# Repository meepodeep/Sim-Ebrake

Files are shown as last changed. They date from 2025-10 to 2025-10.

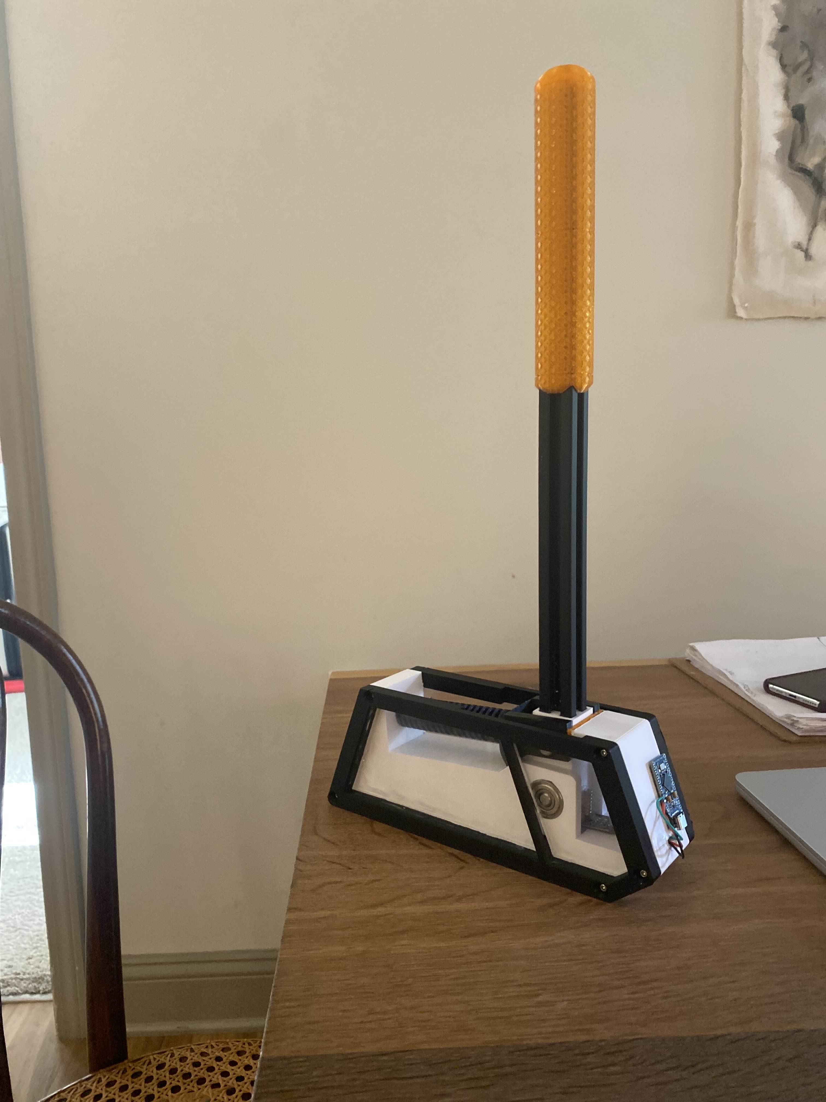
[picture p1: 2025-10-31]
ebrake.jpg

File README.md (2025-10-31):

# 2020 Brake
Racing sim Ebrake that has the same bolt pattern as the Moza!
ebrake

## Why does this exist?
  I wanted an ebrake but all of the existing solutions either looked kind of boring or were extremely expensive (moza handbrake). 
# Build
## Assembly
  1. Press the handle and bottom piece onto the V slot aluminum
  
  
  2. Mark and drill an 8mm hole through the bottom of the aluminum where the top hole in the plastic is
  3. Wire the hall sensor and pro micro like this
     
  
  
  5. Put the pro micro on the front after feeding the wires through the hole and secure it with tape or hot glue
  
  7. Double sided tape the hall sensor here
     
 

  9. Hot glue the magnets here
      
 

  11. Press fit bearings in each side of the base
      
  
  
  13. Put a rod through the bearings and shaft
  14. Attach the spring pivot like this
      
  
  
  16. Insert the spring here
      
  
  
  18. Attach the side panels (optionally add the acrylic inserts)
      
  

## Software
  ### https://github.com/ranenbg/Arduino-FFB-wheel
  1. Download the Xloader folder
  2. Run the .exe
  3. Click upload once you have selected the correct port and the correct hex file as according to the guide on ranebgs github

## BOM
|Item |Quantity |Total price+Shipping|Use In project |Item Source |
|---|---|---|---|---|
|Bearings 8x22x7mm |10pcs min purchase 2 used |$6.36 |Rotates the main pivot |https://www.aliexpress.us/item/3256807915662185.html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 |
|Magnets 5x2mm |10pcs min purchase 1 used |$1.80 |Magnets |https://www.aliexpress.us/item/3256809772407336.html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 |
|KY-035 Hall Sensor |2pcs for 20 cents more these are not very reliable 1 used|$2.85 |Senses the halls (Magnet)|https://www.aliexpress.us/item/3256806209950505.html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 |
|Pro Micro usbc |1x |$7.05 |Controls everything |https://www.aliexpress.us/item/3256806468327207.html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 |
|Spring Blue/whatever color 20x10x80mm|1x |$4.80 |Spring tension |https://www.aliexpress.us/item/3256806244146198.html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 |
|Pins 8x40mm |10pcs min purchase 2 used |$6.78 |pivot points |https://www.aliexpress.us/item/3256806373526334.html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 |
|2020 V slot 350mm |1x |$12.84 |shaft |https://www.aliexpress.us/item/3256803241979487.html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|
|Optional(Laser cut acrylic) |1x |$8 |COOOOL lookin sides |My uni makerspace |
|Tax |Its tax |$2.98 |Taxes | |
|TOTAL | |$53.46 | | |

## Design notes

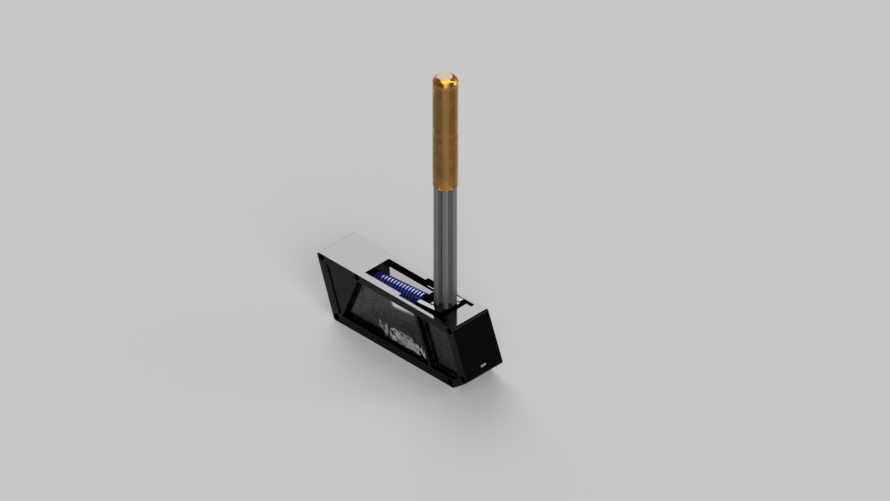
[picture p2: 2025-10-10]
ebrake render.png

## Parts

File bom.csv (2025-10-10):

Item | Quantity | Total price+Shipping | Use In project | Item Source
Bearings 8x22x7mm | 10pcs min purchase 2 used | $6.36 | Rotates the main pivot | https://www.aliexpress.us/item/3256807915662185.html?mp=1
Magnets 5x2mm | 10pcs min purchase 1 used | $1.80 | Magnets | https://www.aliexpress.us/item/3256809772407336.html?mp=1
KY-035 Hall Sensor | 2pcs for 20 cents more these are not very reliable 1 used | $2.85 | Senses the halls (Magnet) | https://www.aliexpress.us/item/3256806209950505.html?mp=1
Pro Micro usbc | 1x | $7.05 | Controls everything | https://www.aliexpress.us/item/3256806468327207.html?mp=1
Spring Blue/whatever color 20x10x80mm | 1x | $4.80 | Spring tension | https://www.aliexpress.us/item/3256806244146198.html?mp=1
Pins 8x40mm | 10pcs min purchase 2 used | $6.78 | pivot points | https://www.aliexpress.us/item/3256806373526334.html?mp=1
2020 V slot 350mm | 1x | $12.84 | shaft | https://www.aliexpress.us/item/3256803241979487.html?mp=1
Optional(Laser cut acrylic) | 1x | $8 | COOOOL lookin sides | My uni makerspace
Tax | Its tax | $2.98 | Taxes
TOTAL |  | $53.46

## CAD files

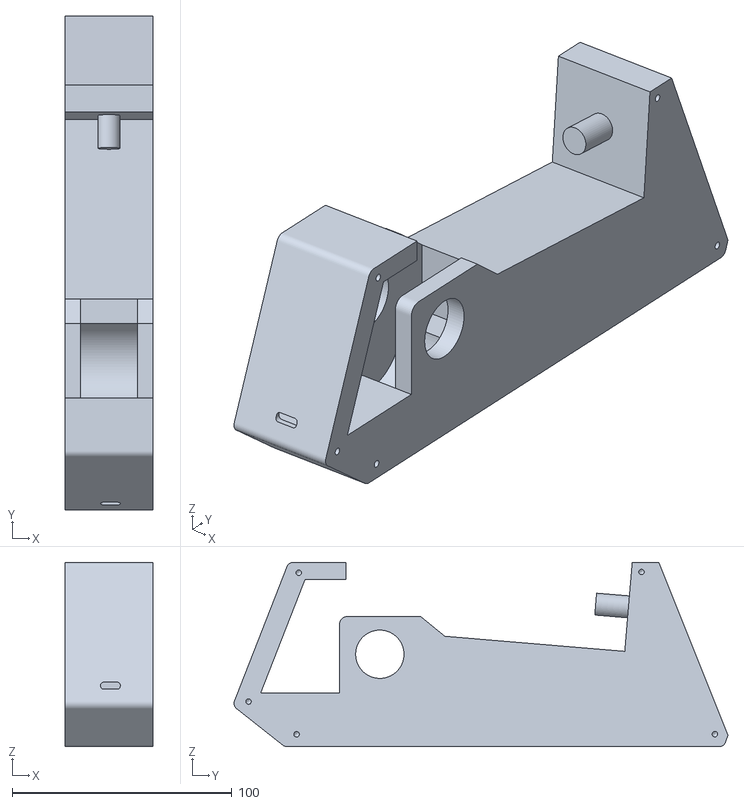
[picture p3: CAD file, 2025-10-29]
STLS/Main.stl
40.0 x 224.9 x 83.9

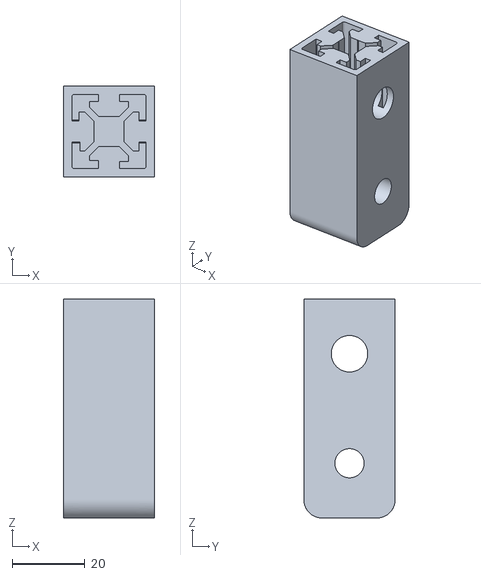
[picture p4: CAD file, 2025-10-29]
STLS/main shaft mount.stl
25.0 x 25.0 x 60.0

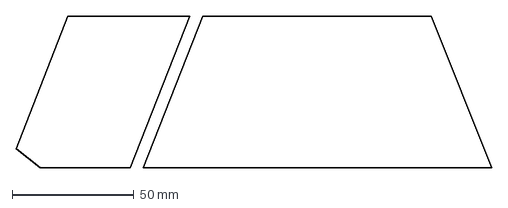
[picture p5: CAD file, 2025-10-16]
side plates.dxf
195.6 x 62.2 mm

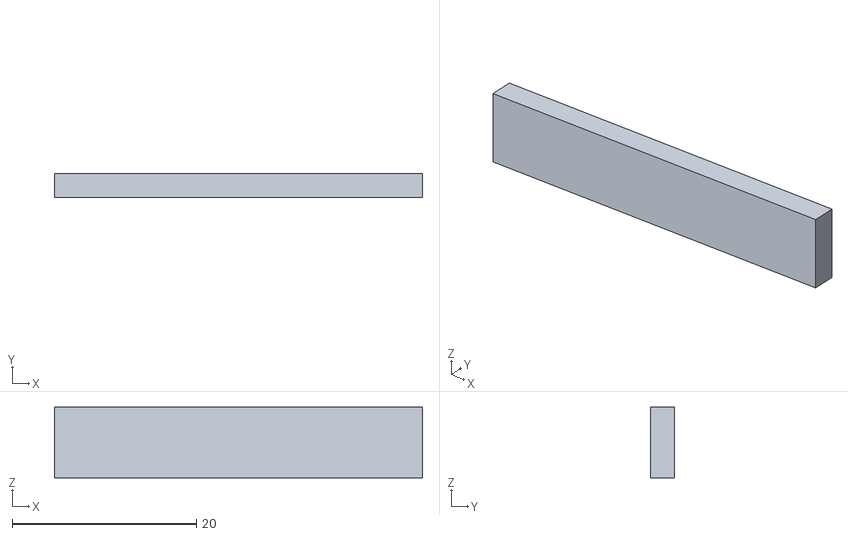
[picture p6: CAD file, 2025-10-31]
STLS/bump stop.stl
40.0 x 2.60 x 7.71

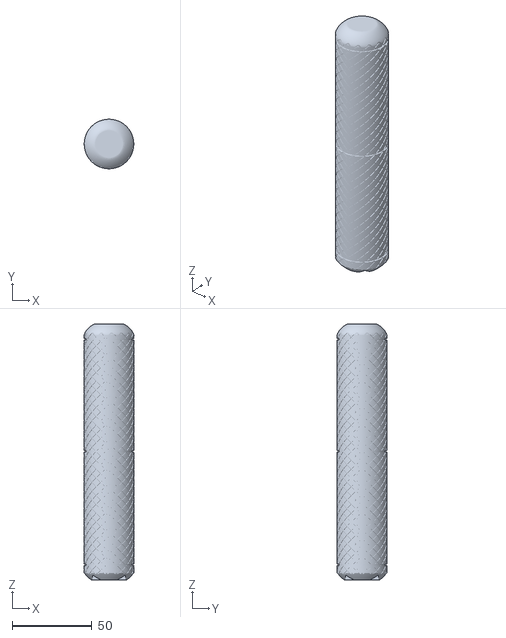
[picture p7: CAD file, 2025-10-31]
STLS/Handle.stl
31.0 x 31.0 x 160.0

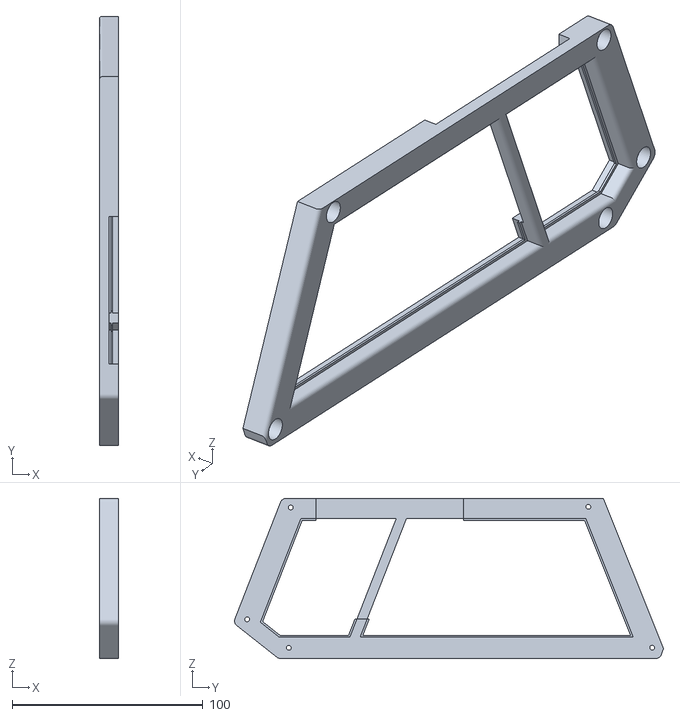
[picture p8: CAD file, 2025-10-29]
STLS/side plate.stl
10.0 x 224.9 x 83.9

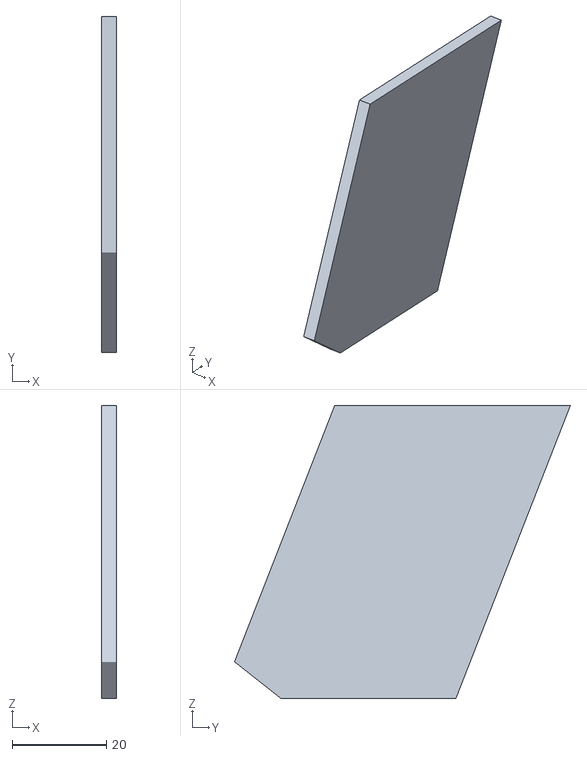
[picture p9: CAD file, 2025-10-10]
STLS/side acrylic small.stl
3.17 x 71.3 x 62.2

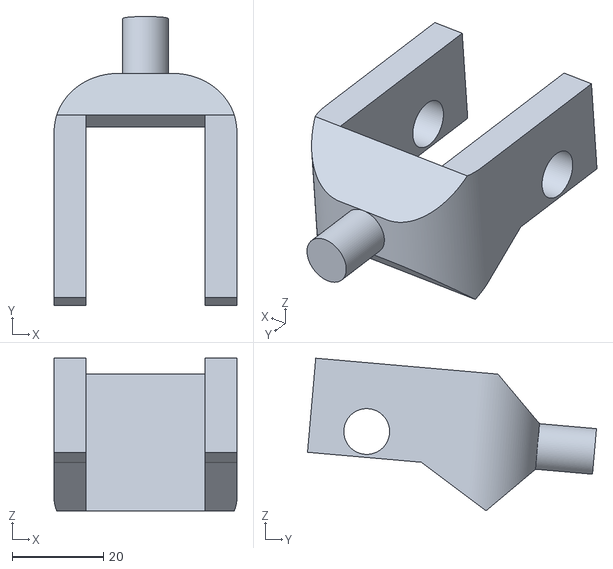
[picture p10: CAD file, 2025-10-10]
STLS/spring pivot.stl
40.0 x 63.2 x 33.4

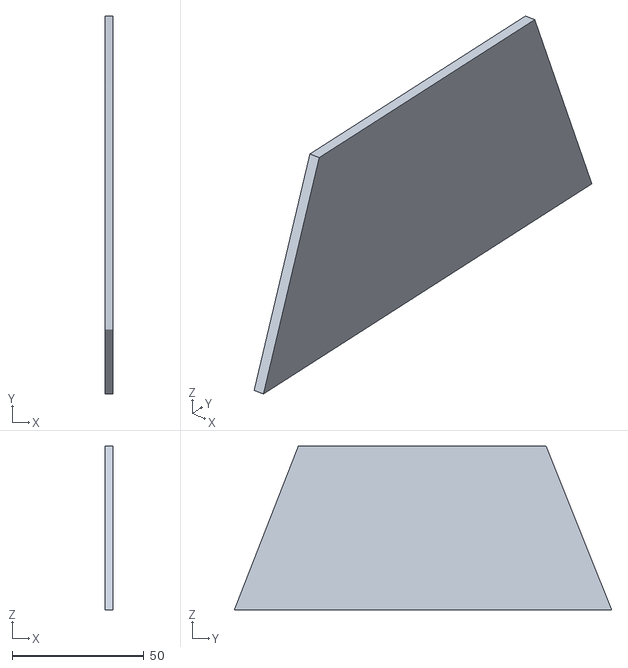
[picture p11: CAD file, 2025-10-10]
STLS/side acrylic big.stl
3.17 x 143.2 x 62.2

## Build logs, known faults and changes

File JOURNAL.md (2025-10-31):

<!--
  ===================    !!READ THIS NOTICE!!   ====================
  DO NOT edit this file manually. Your changes WILL BE OVERWRITTEN!
  This journal is auto generated and updated by Hack Club Blueprint.
  To edit this file, please edit your journal entries on Blueprint.
  ==================================================================
-->

## 10/9/2025 8 PM - Started the 3d model and part sourcing  


So far, I have decided what parts I will be using for the mechanisms, bearings, rods, etc. And started work on the actual model for the project! The electronics of the ebrake will be a Hall effect sensor with a promicro to read the values and send them to the pc. (still working on implementing those into the model)  

## 10/9/2025 9 PM - Added the electronics and springs to the model in fusion  


I added the Pro Micro, hall effect sensor, magnet, and spring. I also modeled the side of the chassis. I also decided to use the university laser to cut acrylic windows into the side panels of the case. Adding materials to the model really makes it pop


## 10/10/2025 - DOCS and CHASSIS  

Today I did a lot of documentation, and I also edited the chassis. Here is a pic from the readme. I added step-by-step instructions with pictures on how to build the ebrake! 
Along with the readme I also made my BOM today, heres that in sheets.
But the most interesting part of what I did was add moza handbrake mounting holes and changed the chassis design!


## 10/31/2025 - Assembled everything and redesigned some parts  

I worked on assembling the thing. I soldered all the parts, I got the windows laser cut. And re fit the tolerance for the aluminum mount and for the handle.


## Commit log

2025-10-10 changed the bearing and main rod diameter
2025-10-10 all of the stls
    [Handle.stl, Left side.stl, Main.stl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]
2025-10-10 Added BOM
    [Ebrake BOM - Sheet1.csv]
2025-10-10 Create Ebrake BOM.csv
    [Ebrake BOM.csv]
2025-10-10 Spring Cleaning
    [Handle.stl, Left side.stl, Main.stl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]
2025-10-10 renanmed bom
    [bom.csv]
2025-10-16 updated tolerance
    [main shaft mount.stl, side plates.dxf]
2025-10-29 updated models for tolerance
    [Left side.stl, Main.stl, Right side.stl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]
2025-10-31 updated some tolerance
    [Handle.stl, bump stop.stl]
